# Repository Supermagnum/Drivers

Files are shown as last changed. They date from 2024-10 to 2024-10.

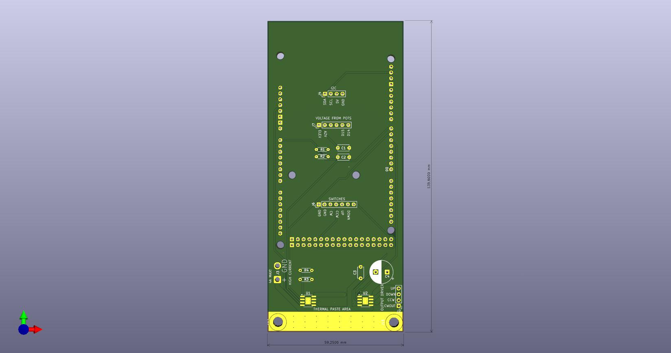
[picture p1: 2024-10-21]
K3NG-rotator-shield.jpg

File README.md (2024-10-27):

This shield fits Arduino Mega 2560.
Including the items in the BOM, you will need:
Shield Stacking Headers compatible with Arduino MEGA 2560 
Each set has 5x1*8p header, 1x1*10p header, 1x2*18p header, 1x2*3p header
Arduino Mega 2560 Rev3 
Suitable USB cable, soldering iron,suitable wires.

<a href="https://www.pcbway.com/project/shareproject/K3NG_rotator_shield_for_Arduino_Mega_2560_f1b5a363.html">PCB from PCBWay</a>

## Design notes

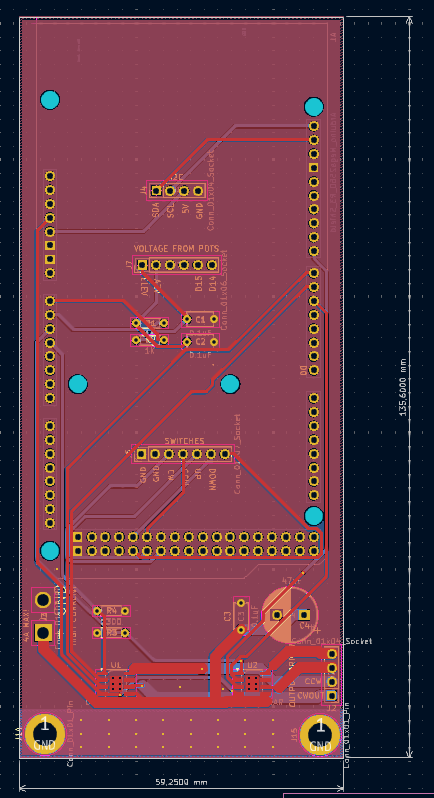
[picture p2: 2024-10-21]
rotator-shield.png

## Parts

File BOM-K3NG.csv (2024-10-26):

Reference | Value | Datasheet | Footprint | Qty | DNP | mfr
C1,C2,C3 | 0.1uF | ~ | Capacitor_THT:C_Disc_D4.7mm_W2.5mm_P5.00mm | 3 |  | K104K10X7RF5UH5
C4 | 47uF | ~ | Capacitor_THT:CP_Radial_D10.0mm_P5.00mm | 1 |  | RNU1H470MDN1PH
J2,J4 | Conn_01x04_Socket | ~ | Connector_PinHeader_2.54mm:PinHeader_1x04_P2.54mm_Vertical | 2 |  | 1725672
J6 | Conn_01x07_Socket | ~ | Connector_PinHeader_2.54mm:PinHeader_1x07_P2.54mm_Vertical | 1 |  | 1725708
J7 | Conn_01x06_Socket | ~ | Connector_PinHeader_2.54mm:PinHeader_1x06_P2.54mm_Vertical | 1 |  | 1725698
R1,R2 | 1K | ~ | Resistor_THT:R_Axial_DIN0204_L3.6mm_D1.6mm_P5.08mm_Horizontal | 2 |  | YR1B1K0CC
R3,R4 | 1300 | ~ | Resistor_THT:R_Axial_DIN0204_L3.6mm_D1.6mm_P5.08mm_Horizontal | 2 |  | MFR-25FBF52-1K3
U1,U2 | DRV8251ADDAR |  | Package_SO:SOIC-8-1EP_3.9x4.9mm_P1.27mm_EP2.29x3mm_ThermalVias | 2

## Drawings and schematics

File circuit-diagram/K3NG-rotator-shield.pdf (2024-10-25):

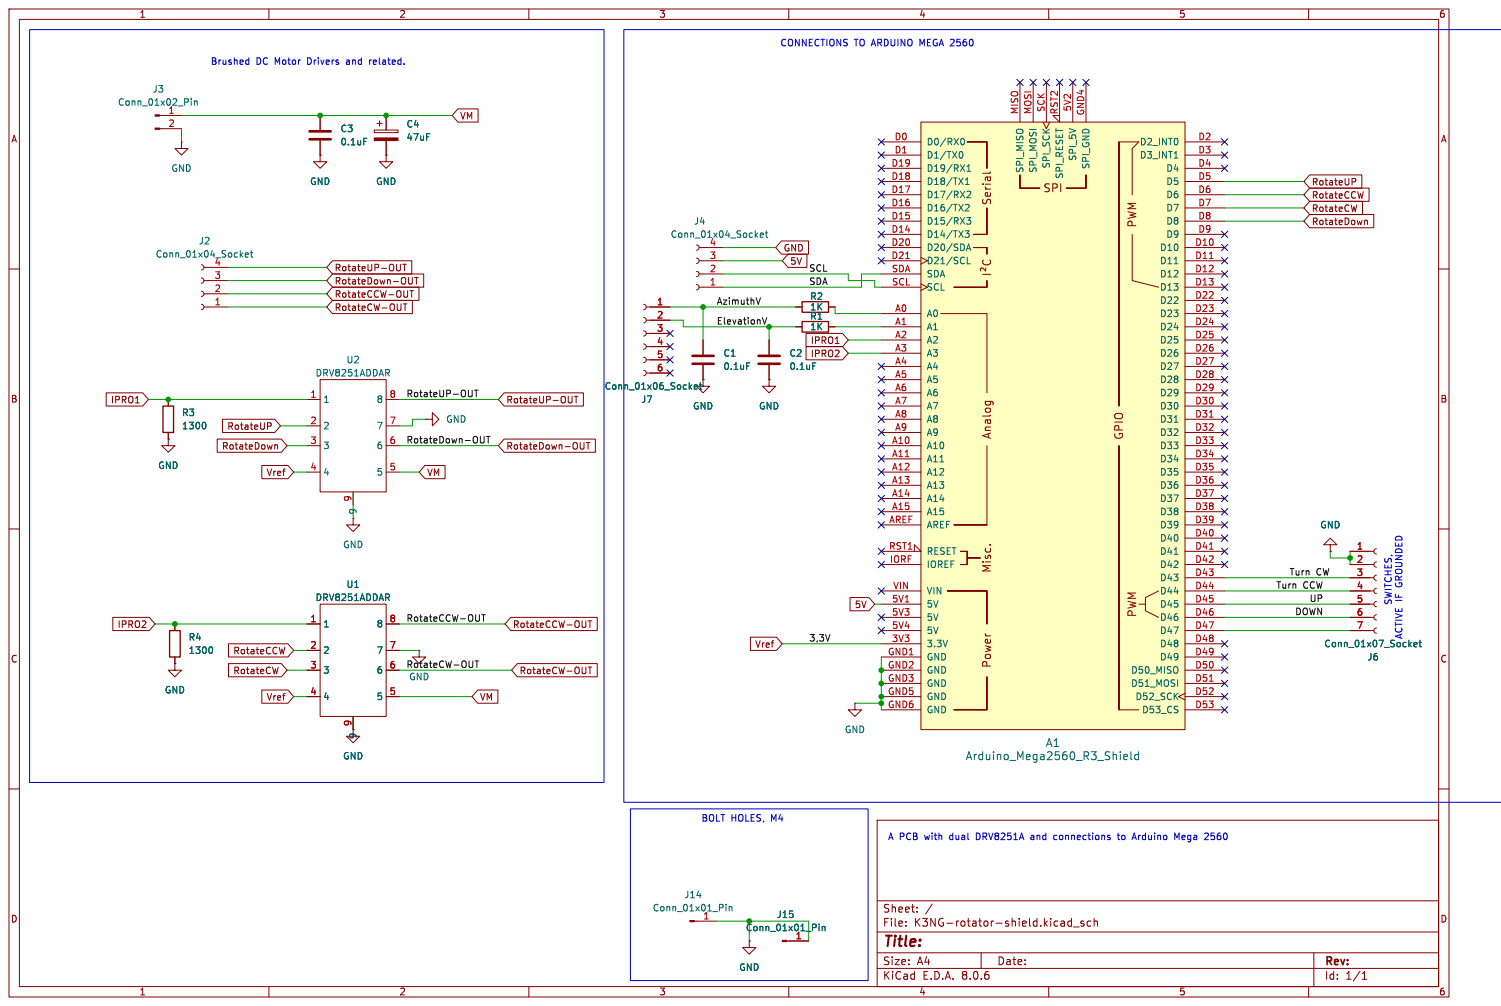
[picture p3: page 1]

5V RotateDown-OUT VM
SDA RotateCW-OUT RotateCCW-OUT RotateUP-OUT RotateDown-OUT
RotateUP-OUT VM

RotateCCW-OUT RotateUP-OUT RotateDown-OUT RotateCW-OUT

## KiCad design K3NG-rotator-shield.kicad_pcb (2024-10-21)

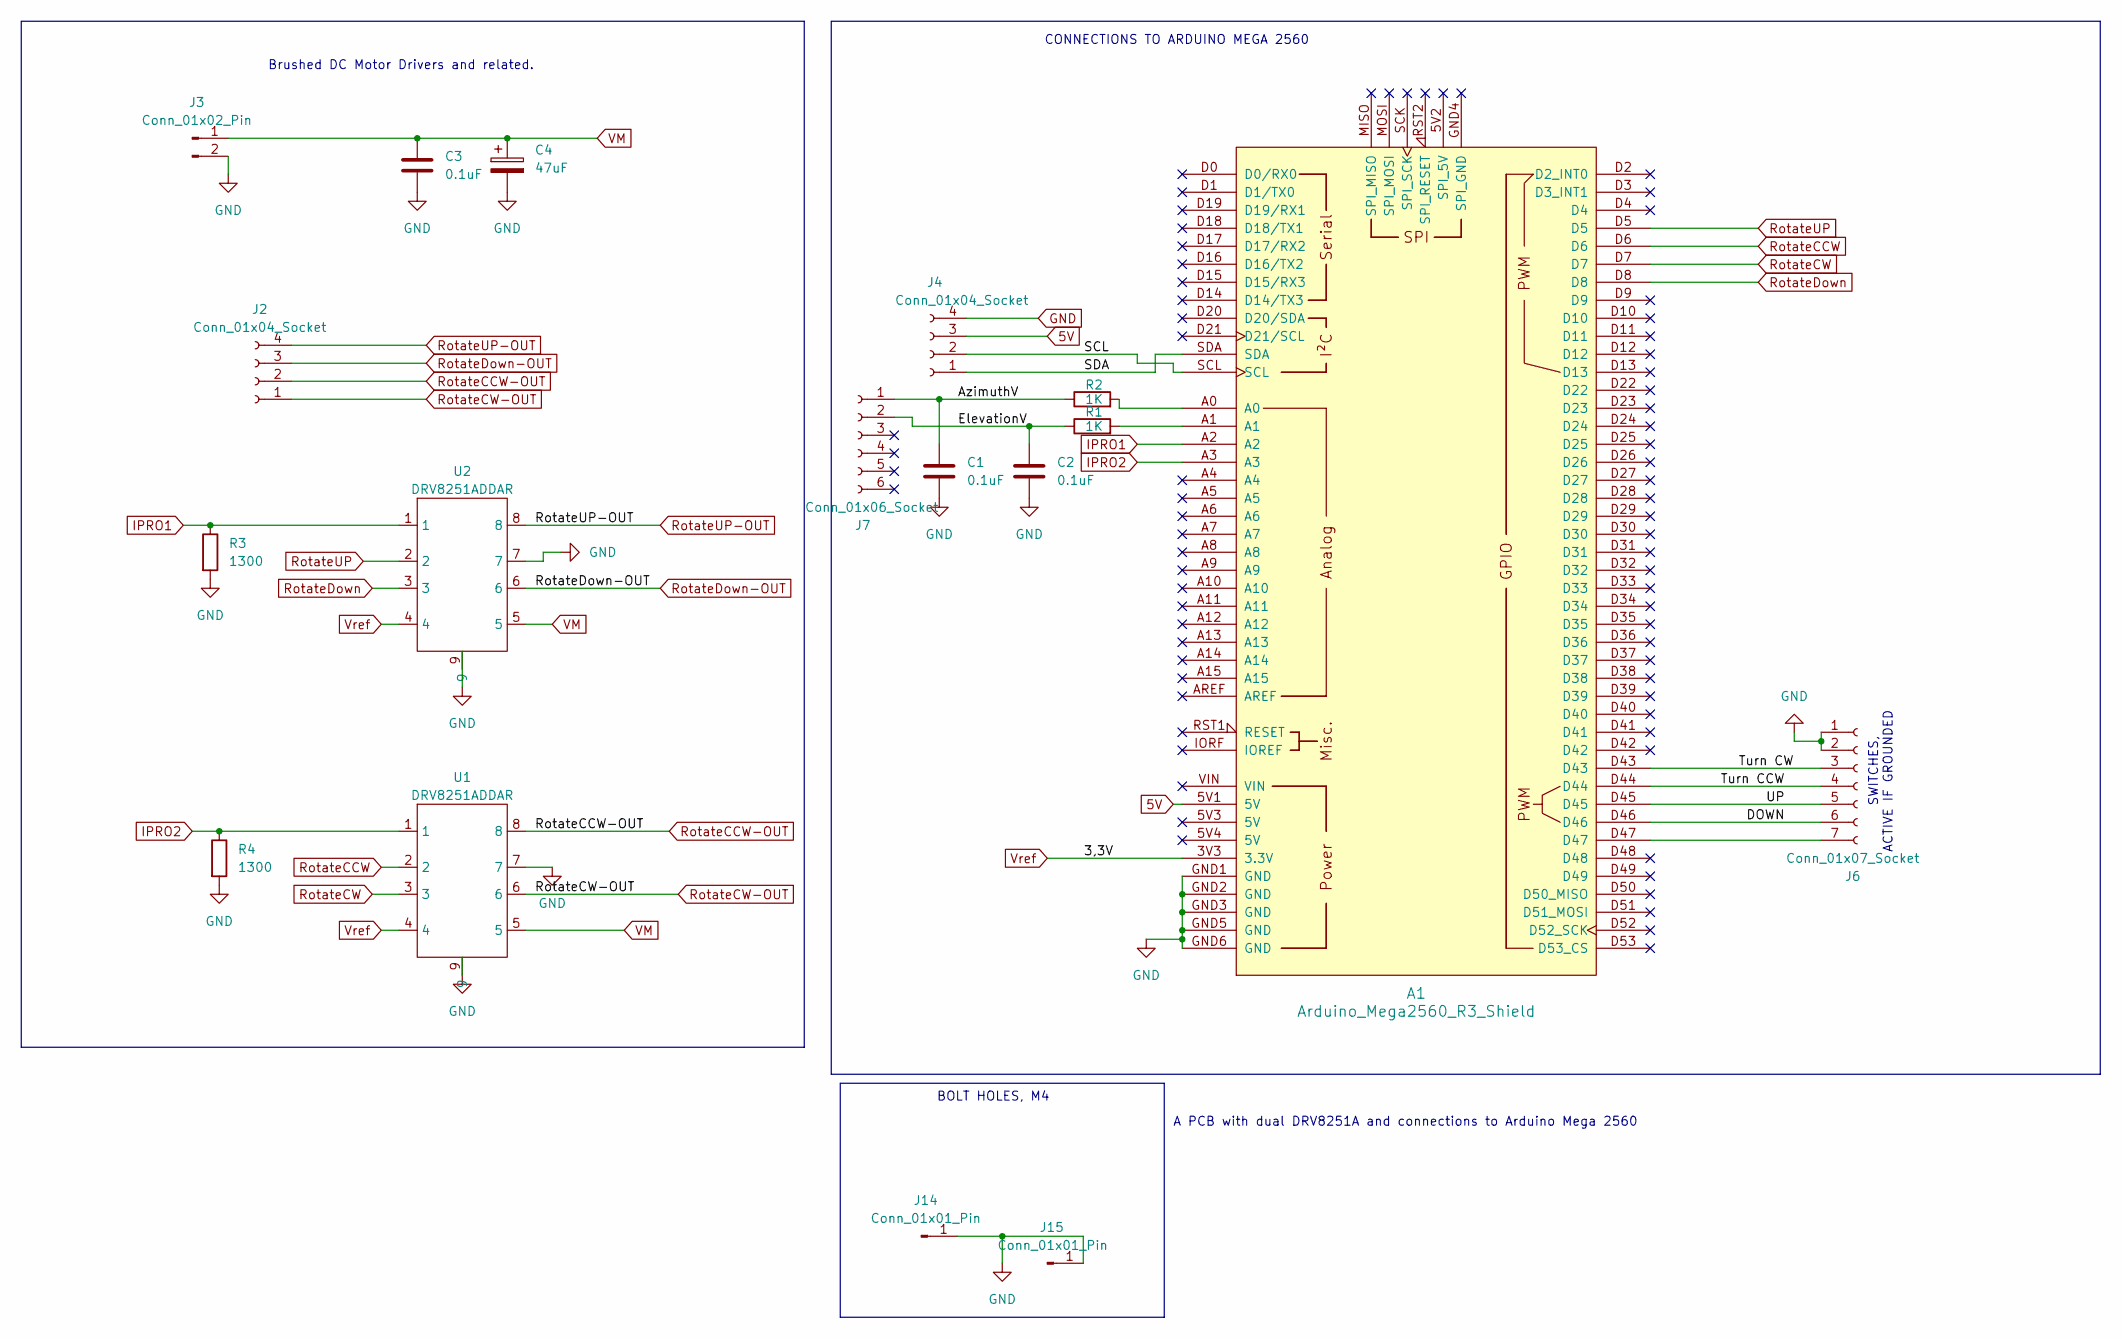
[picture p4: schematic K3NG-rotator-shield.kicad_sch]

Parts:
A1: Arduino_Mega2560_R3_Shield; Arduino_Mega2560_R3_K3NG
C1, C2, C3: 0.1uF; C_Disc_D4.7mm_W2.5mm_P5.00mm
C4: 47uF; CP_Radial_D10.0mm_P5.00mm
J2, J4: Conn_01x04_Socket; PinHeader_1x04_P2.54mm_Vertical
J3: Conn_01x02_Pin; SolderWire-1.5sqmm_1x02_P6mm_D1.7mm_OD3mm
J6: Conn_01x07_Socket; PinHeader_1x07_P2.54mm_Vertical
J7: Conn_01x06_Socket; PinHeader_1x06_P2.54mm_Vertical
J14, J15: Conn_01x01_Pin; MountingHole_4.3mm_M4_DIN965_Pad
R1, R2: 1K; R_Axial_DIN0204_L3.6mm_D1.6mm_P5.08mm_Horizontal
R3, R4: 1300; R_Axial_DIN0204_L3.6mm_D1.6mm_P5.08mm_Horizontal
U1, U2: DRV8251ADDAR; SOIC-8-1EP_3.9x4.9mm_P1.27mm_EP2.29x3mm_ThermalVias

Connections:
5V: A1.5V1 (5V), J4.3
/AzimuthV: C1.1, J7.1, R2.1
/DOWN: A1.D46, J6.6
/ElevationV: C2.1, J7.2, R1.1
/SCL: A1.SCL, J4.2
/SDA: A1.SDA, J4.1
/Turn CCW: A1.D44, J6.4
/Turn CW: A1.D43, J6.3
/UP: A1.D45, J6.5
GND: A1.GND1 (GND), A1.GND2 (GND), A1.GND3 (GND), A1.GND5 (GND), A1.GND6 (GND), C1.2, C2.2, C3.2, C4.2, J3.2, J4.4, J6.1, J6.2, J14.1, J15.1, R3.2, R4.2, U1.7, U1.9, U2.7, U2.9
IPRO1: A1.A2, R3.1, U2.1
IPRO2: A1.A3, R4.1, U1.1
unnamed: A1.A0, R2.2
unnamed: A1.A1, R1.2
unnamed: A1.D47, J6.7
RotateCCW: A1.D6, U1.2
RotateCCW-OUT: J2.2, U1.8
RotateCW: A1.D7, U1.3
RotateCW-OUT: J2.1, U1.6
RotateDown: A1.D8, U2.3
RotateDown-OUT: J2.3, U2.6
RotateUP: A1.D5, U2.2
RotateUP-OUT: J2.4, U2.8
VM: C3.1, C4.1, J3.1, U1.5, U2.5
Vref: A1.3V3 (3.3V), U1.4, U2.4

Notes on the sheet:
BOLT HOLES, M4
SWITCHES, ACTIVE IF GROUNDED
A PCB with dual DRV8251A and connections to Arduino Mega 2560
CONNECTIONS TO ARDUINO MEGA 2560
Brushed DC Motor Drivers and related.

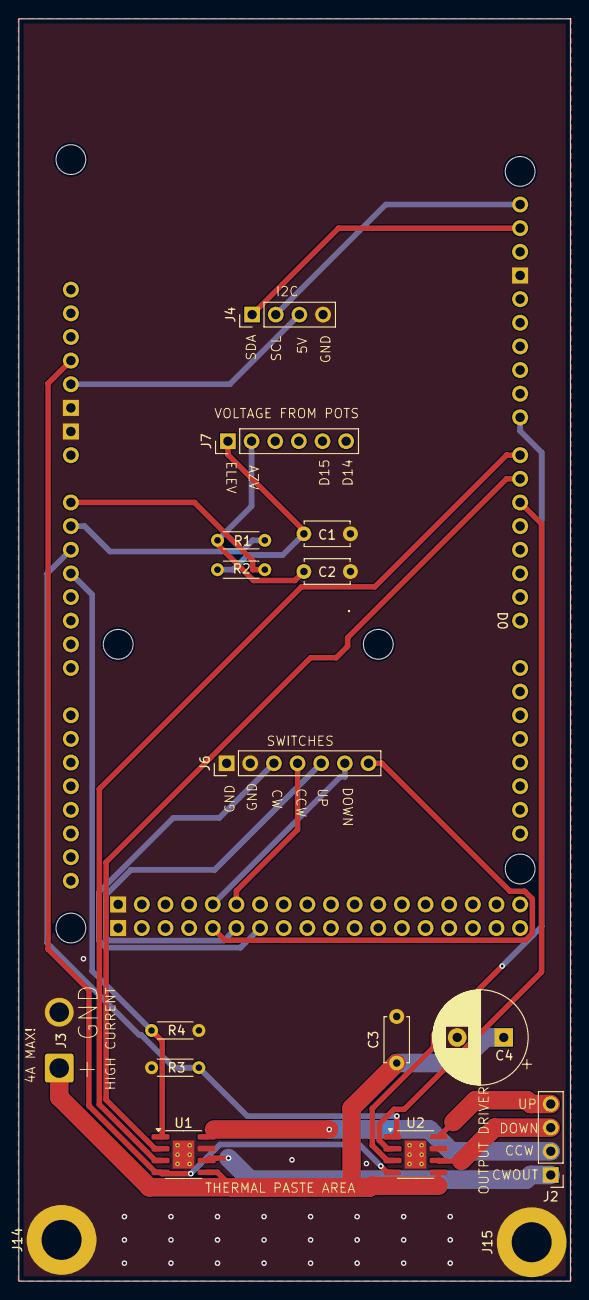
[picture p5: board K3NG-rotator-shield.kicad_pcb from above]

Board: 2 copper layers, 59.2 x 135.6 mm, 18 parts (0 on the bottom side), 25 nets.
